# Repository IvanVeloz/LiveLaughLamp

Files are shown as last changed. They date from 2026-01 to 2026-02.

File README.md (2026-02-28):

# Introduction

_Live, Laugh, Lamp_ is a premium LED lamp for the Fluval Liv aquarium. It's inspired by Fluval's own Plant line of LED lights: a lamp with high CRI LEDs, colors tuned for plant growth, and programmable through a smartphone.

### Features
* Powered by USB like the original
* High CRI, above 90, provided by quality Cree LEDs
* Higher power output, e.g. for folks dosing Flourish Excel
* Programmable through HomeAssistant
* Colors are adjustable and dimmable
* Extremely high dynamic range —super fine adjustments in low light settings
* Hacker friendly, design files available
   * Customize with any color Cree XP-G3 or compatible LEDs
   * Every LED gets its own PWM channel
   * Easy firmware setup thanks to ESPHome
 
# Motivation(s)
I bought the first batch of Fluval Liv as soon as it hit the shelves. I loved its aesthetic and its clever filtration system. One thing I wished was for it to have a little timer built into its light. So one thing led to another and I designed this lamp. 

### Having a real night light
But why such a sophisticated lamp for this nano tank? Well, I have Thai Micro Crabs. They are nocturnal and I hardly get to see them. So I was always wishing for a dimmable lamp (with a red light) to watch them on those 3AM water breaks. Many animals don't react much to red light at night, and it doesn't wake you up either. So I wanted this on my bedroom aquarium.

### An enjoyable experience for everybody
Another reason is I have a Fluval Plant 4.0 on a bigger tank. I _love_ running it at 2% brightness in the evenings. I only run its red and warm white LEDs in the evening and it creates a very nice warm white light with pink accents. It's very easy on my eyes. I can tell the fish enjoy it too: the nocturnal ones start to wake up and everybody else starts to wind down.

### Nano tanks deserve advanced equipment
Finally, I just think nano tanks should get the same kind of high quality, advanced equipment that larger tanks get. For example, it's hard to find good nano syphons, nano wave makers, CO₂ systems, etc. This light is my small contribution.

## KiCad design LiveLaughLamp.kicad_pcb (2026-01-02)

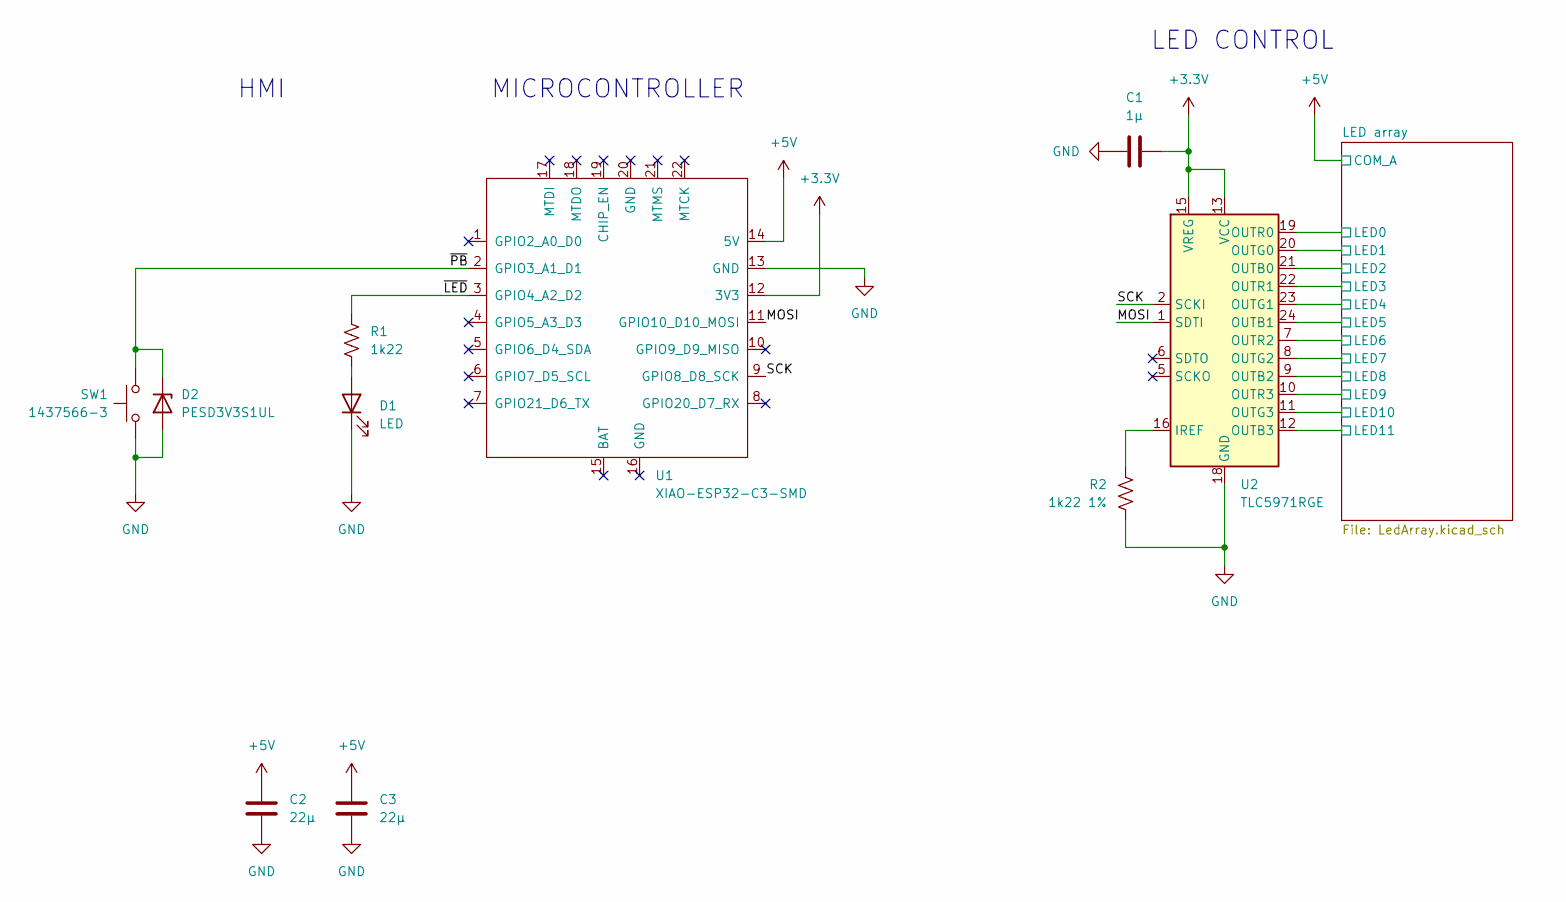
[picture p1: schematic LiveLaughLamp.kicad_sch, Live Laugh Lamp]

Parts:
C1: 1µ; C_0402_1005Metric
C2, C3: 22µ; C_0805_2012Metric
D1: LED; LED_0603_1608Metric
D2: PESD3V3S1UL; D_SOD-882
R1: 1k22; R_0402_1005Metric
R2: 1k22 1%; R_0402_1005Metric
SW1: 1437566-3; SW_SPST_B3U-3000P-B
U1: XIAO-ESP32-C3-SMD; XIAO-ESP32C3-SMD
U2: TLC5971RGE; Texas_RGE0024H_VQFN-24-1EP_4x4mm_P0.5mm_EP2.7x2.7mm_Thermal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

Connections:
+3.3V: C1.2, U1.12 (3V3), U2.13 (VCC), U2.15 (VREG)
+5V: C2.1, C3.1, U1.14 (5V); also elsewhere on the board
/LED array/LED0: U2.19 (OUTR0); also elsewhere on the board
/LED array/LED1: U2.20 (OUTG0); also elsewhere on the board
/LED array/LED2: U2.21 (OUTB0); also elsewhere on the board
/LED array/LED3: U2.22 (OUTR1); also elsewhere on the board
/LED array/LED4: U2.23 (OUTG1); also elsewhere on the board
/LED array/LED5: U2.24 (OUTB1); also elsewhere on the board
/LED array/LED6: U2.7 (OUTR2); also elsewhere on the board
/LED array/LED7: U2.8 (OUTG2); also elsewhere on the board
/LED array/LED8: U2.9 (OUTB2); also elsewhere on the board
/LED array/LED9: U2.10 (OUTR3); also elsewhere on the board
/LED array/LED10: U2.11 (OUTG3); also elsewhere on the board
/LED array/LED11: U2.12 (OUTB3); also elsewhere on the board
/MOSI: U1.11 (GPIO10_D10_MOSI), U2.1 (SDTI)
/SCK: U1.9 (GPIO8_D8_SCK), U2.2 (SCKI)
/~LED: R1.1, U1.3 (GPIO4_A2_D2)
/~PB: D2.1 (K), SW1.1, U1.2 (GPIO3_A1_D1)
GND: C1.1, C2.2, C3.2, D1.1 (K), D2.2 (A), R2.2, SW1.2, U1.13 (GND), U2.18 (GND), U2.25 (GND)
unnamed: D1.2 (A), R1.2
unnamed: R2.1, U2.16 (IREF)

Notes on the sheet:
HMI
MICROCONTROLLER
LED CONTROL

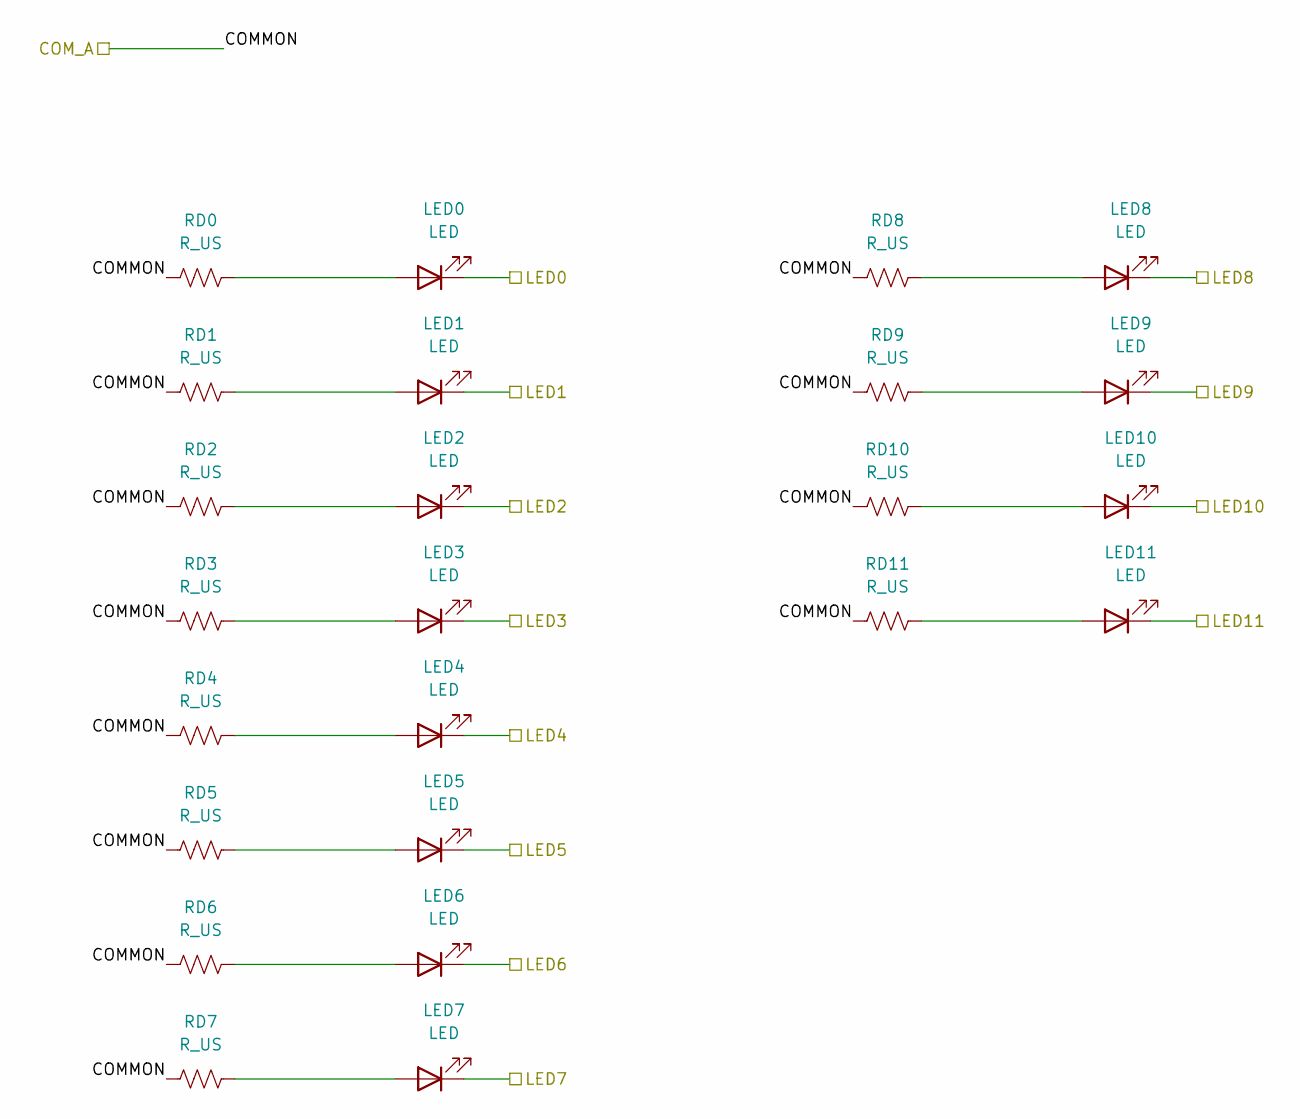
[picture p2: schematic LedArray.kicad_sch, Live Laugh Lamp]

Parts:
LED0, LED1, LED2, LED3, LED4, LED5, LED6, LED7, LED8, LED9, LED10, LED11: LED; LED_Cree-XP-G
RD0, RD1, RD2, RD3, RD4, RD5, RD6, RD7, RD8, RD9, RD10, RD11: R_US; R_1206_3216Metric

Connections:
+5V: RD0.2, RD1.2, RD2.2, RD3.2, RD4.2, RD5.2, RD6.2, RD7.2, RD8.2, RD9.2, RD10.2, RD11.2; also elsewhere on the board
/LED array/LED0: LED0.1 (K); also elsewhere on the board
/LED array/LED1: LED1.1 (K); also elsewhere on the board
/LED array/LED2: LED2.1 (K); also elsewhere on the board
/LED array/LED3: LED3.1 (K); also elsewhere on the board
/LED array/LED4: LED4.1 (K); also elsewhere on the board
/LED array/LED5: LED5.1 (K); also elsewhere on the board
/LED array/LED6: LED6.1 (K); also elsewhere on the board
/LED array/LED7: LED7.1 (K); also elsewhere on the board
/LED array/LED8: LED8.1 (K); also elsewhere on the board
/LED array/LED9: LED9.1 (K); also elsewhere on the board
/LED array/LED10: LED10.1 (K); also elsewhere on the board
/LED array/LED11: LED11.1 (K); also elsewhere on the board
unnamed: LED0.2 (A), RD0.1
unnamed: LED1.2 (A), RD1.1
unnamed: LED2.2 (A), RD2.1
unnamed: LED3.2 (A), RD3.1
unnamed: LED4.2 (A), RD4.1
unnamed: LED5.2 (A), RD5.1
unnamed: LED6.2 (A), RD6.1
unnamed: LED7.2 (A), RD7.1
unnamed: LED8.2 (A), RD8.1
unnamed: LED9.2 (A), RD9.1
unnamed: LED10.2 (A), RD10.1
unnamed: LED11.2 (A), RD11.1

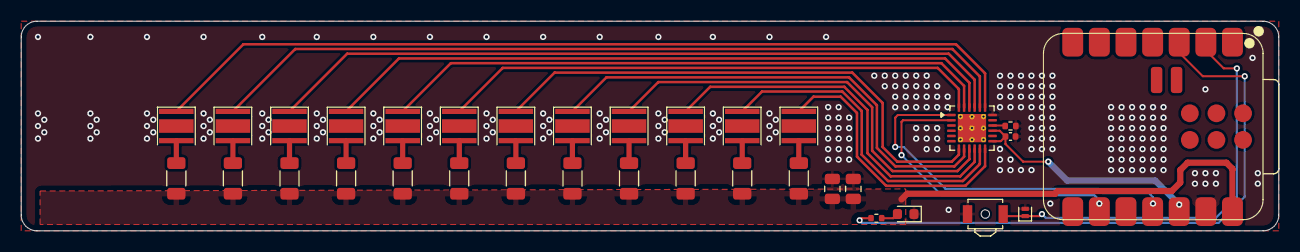
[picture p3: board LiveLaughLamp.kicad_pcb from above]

Board: 2 copper layers, 120.0 x 20.0 mm, 34 parts (0 on the bottom side), 33 nets.

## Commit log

2026-01-01 Add project with Cree XP-G LEDs and PCA9685 controller
    [LedArray.kicad_sch, LiveLaughLamp.kicad_pcb, LiveLaughLamp.kicad_sch]
2026-01-01 Swap LED controller for TLC5971
    [LedArray.kicad_sch, LiveLaughLamp.kicad_pcb, LiveLaughLamp.kicad_sch]
2026-01-01 Add thermal sink for Xiao board. Add JLC fabrication metadata.
    [LiveLaughLamp.kicad_pcb, LiveLaughLamp.kicad_sch]
2026-01-02 Untent thermal vias for Xiao module
    [LiveLaughLamp.kicad_pcb]
2026-01-17 Change some component values for better sourcing
    [LiveLaughLamp.kicad_sch]
2026-02-28 Add README content for Live, Laugh, Lamp LED lamp
    Added detailed introduction and features for the Live, Laugh, Lamp LED lamp, including motivations for its design and benefits for nano tanks.

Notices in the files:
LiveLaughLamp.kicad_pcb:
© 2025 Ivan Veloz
